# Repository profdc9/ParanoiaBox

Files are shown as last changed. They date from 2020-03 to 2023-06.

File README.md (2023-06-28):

# ParanoiaBox
The ParanoiaBox by Daniel L. Marks

The ParanoiaBox is a standalone open hardware/software encryption device based on the STM32F103CBT6 processor.  On this device, messages may be composed, encrypted, decrypted, and viewed.  The device is an experiment in encryption minimalism, presenting a minimal attack surface by using a small microcontroller rather than a full personal computer with a complex operating system, while providing the functionality needed to transact encrypted messages between humans through insecure networks.  The device is connected to a NTSC television and a PS/2 keyboard for user input and control.  There are two micro SD card slots, one for ciphertext and the other for plaintext used to transact files.  There is a hardware random number generator based on avalanche noise generated in two transistors.  A picture of the complete PCB of the device can be seen below:

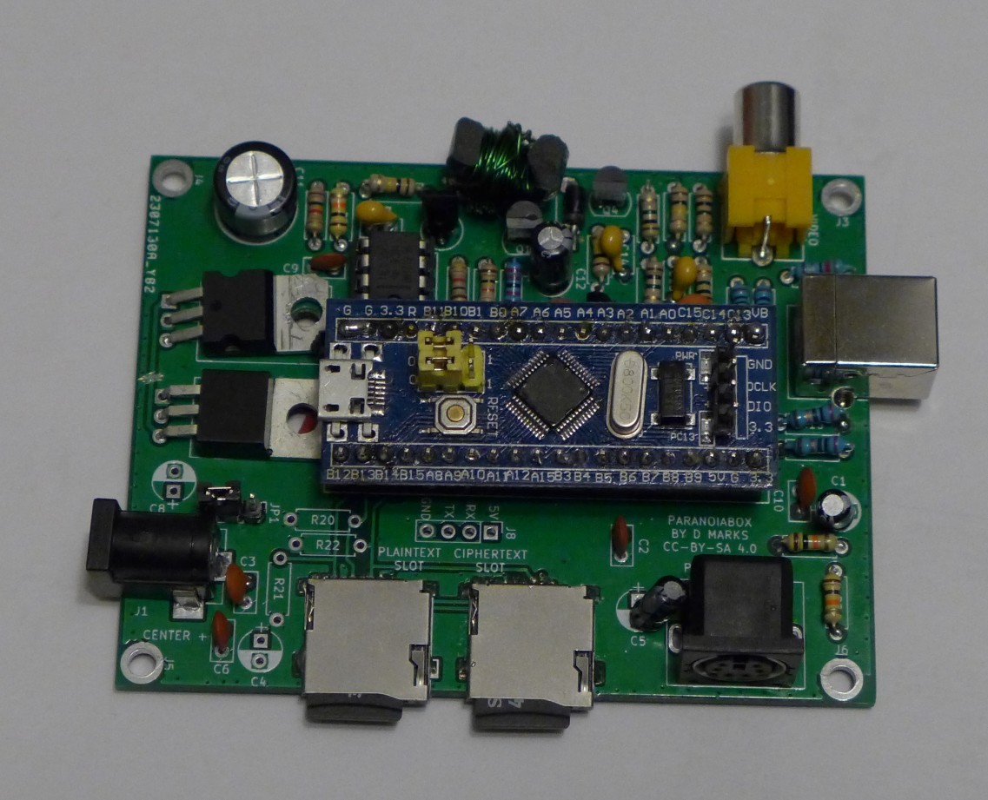
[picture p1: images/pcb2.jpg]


At the top of the board is a RCA composite video connector.  At the right is a USB B connector that can be used to program the microcontroller.  At the lower right is a female PS/2 keyboard connector.  At the bottom are two SD card slots.  Finally, at the left is a barrel jack for 7 to 12 volt DC input power.  Except for the micro SD card slots, the PCB is all through assembly so it can be assembled more easily using simple tools.

The hardware is licensed under the Creative Commons CC-BY-SA 4.0 license.  The software written by D. L. Marks is licensed under the zlib license.  All other libraries are licensed under the licenses as described in the corresponding source files.  This hardware and software is provided under these licenses to be used at your own risk.  

THE HARDWARE AND SOFTWARE IS PROVIDED "AS IS", WITHOUT WARRANTY OF ANY KIND, EXPRESS OR IMPLIED, INCLUDING BUT NOT LIMITED TO THE WARRANTIES OF MERCHANTABILITY, FITNESS FOR A PARTICULAR PURPOSE AND NONINFRINGEMENT. IN NO EVENT SHALL THE AUTHORS OR COPYRIGHT HOLDERS BE LIABLE FOR ANY CLAIM, DAMAGES OR OTHER LIABILITY, WHETHER IN AN ACTION OF CONTRACT, TORT OR OTHERWISE, ARISING FROM, OUT OF OR IN CONNECTION WITH THE HARDWARE AND SOFTWARE OR THE USE OR OTHER DEALINGS IN THE HARDWARE AND SOFTWARE.

The project uses Advanced Encryption Standard AES256-GCM Galois Counter Mode as an authenticated symmetric encryption.  The keys are derived from shared secrets based on then Elliptic Curve Diffie-Hellmann (ECDH) 25519.  The keys are encrypted using a passphrase and AES256-GCM and stored in the flash memory of the microcontroller.  The encrypted data and public key certificates are base64 encoded so that they can be transmitted through e-mail as text files.  The library used is the Arduino Cryptography Library by Rhys Weatherley:

https://rweather.github.io/arduinolibs/crypto.html

The project uses the stm32duino libraries located here:

https://github.com/rogerclarkmelbourne/Arduino_STM32

All other Arduino libraries are provided in the libraries directory in this project, including those that provide the FAT fs, NTSC video output, PS/2 keyboard input, and cryptography.  To enter a message into the microcontroller, there is a full-screen text editor:

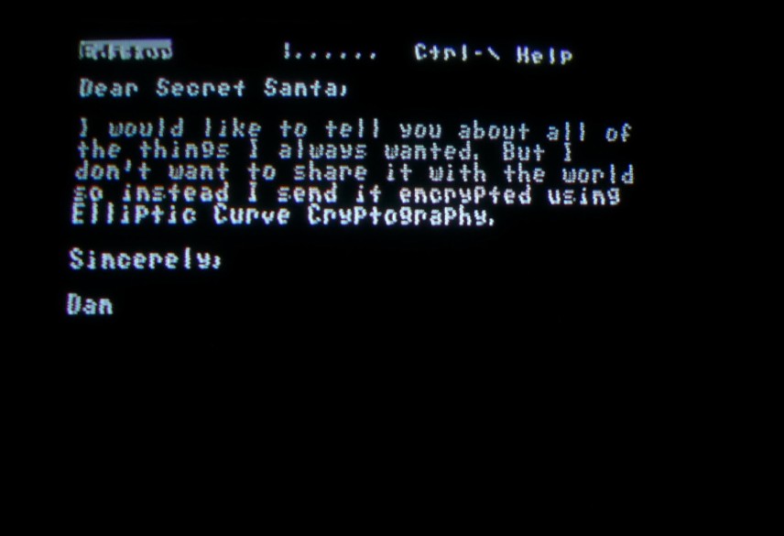
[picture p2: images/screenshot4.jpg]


There is a the built-in full-screen editor used to compose short messages.  Files may be selected from the SD cards for editing, encryption, or decryption:

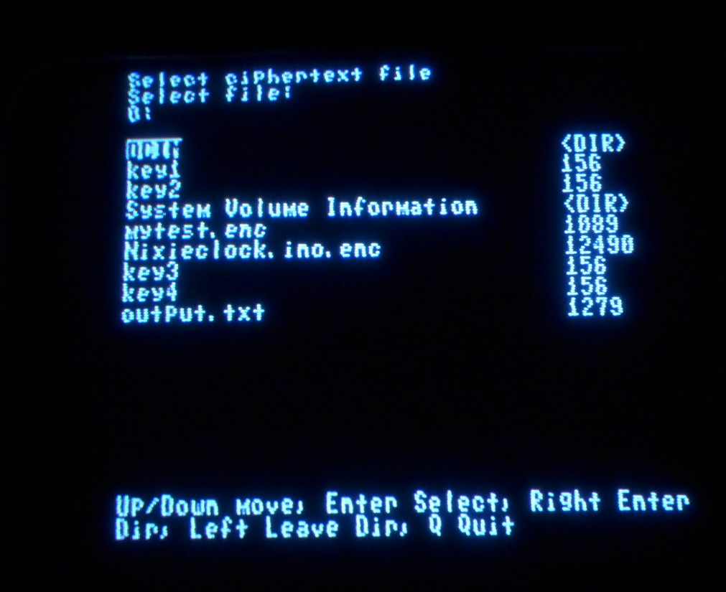
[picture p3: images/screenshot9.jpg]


This is the key manager screen from which the AES 256 symmetric, ECDH25519 private or public keys are selected:

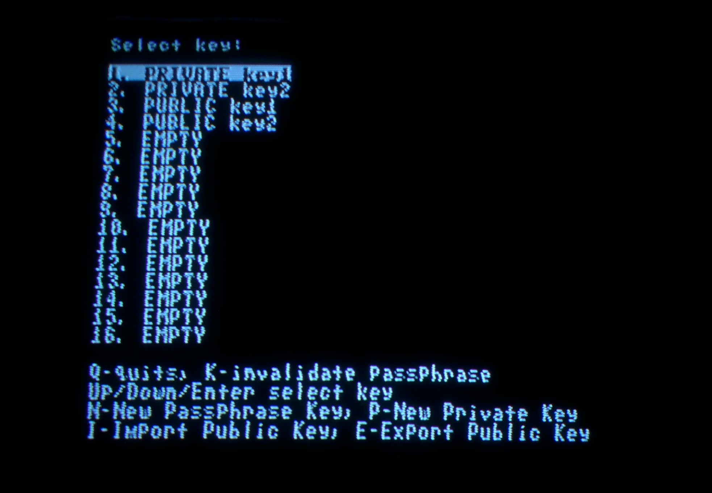
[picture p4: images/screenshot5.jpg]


To encrypt/decrypt using AES, a AES key is selected.  To encrypt/decrypt using ECDH25519, a private and public key pair are selected.   Then one selects a file to encrypt or decrypt.  Separate SD cards must be used for encryption and decryption to ensure that both are not available together to be compared.  One can export a public key certificate from a private key.  After selection, the main screen shows the selected keys:

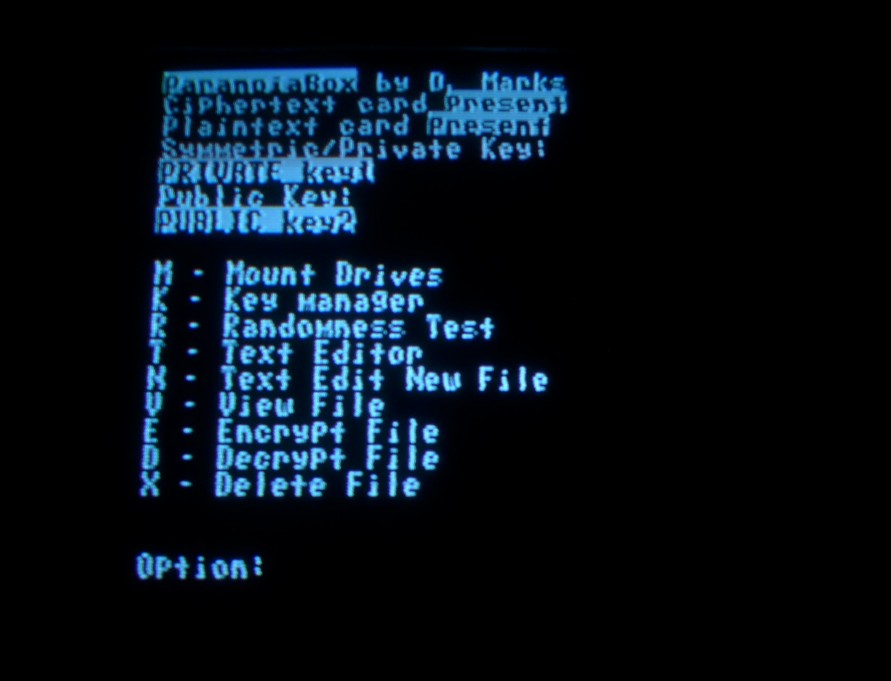
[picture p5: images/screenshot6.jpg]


The message is then encrypted by selecting the file from the card in the plaintext slot using the (E)ncrypt option.  Then the encrypted file is placed on the card in the ciphertext slot.  You can view this file which is text encoded to be easily transmitted over email:

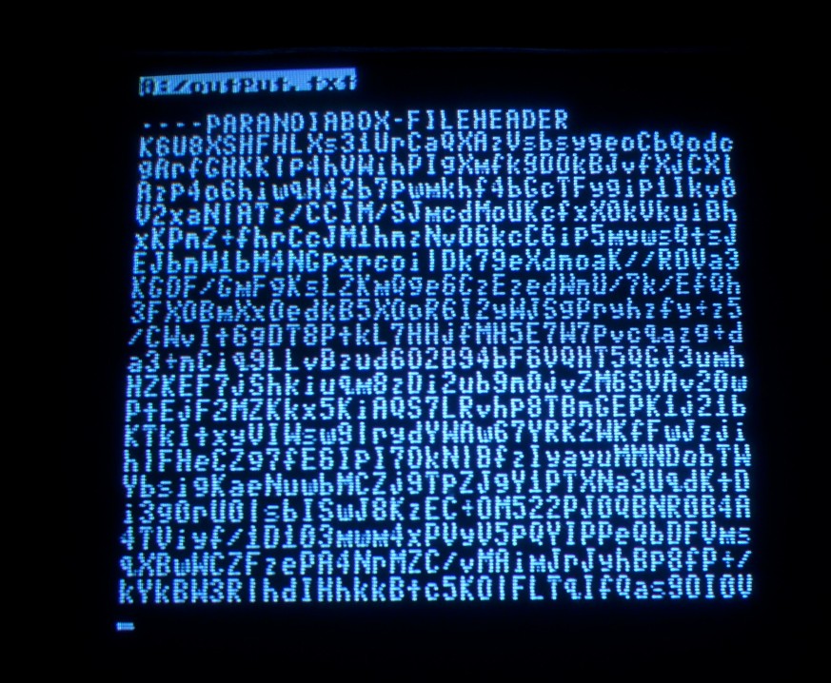
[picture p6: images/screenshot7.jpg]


Once it has been received, it can be decrypted and viewed, and it looks like the original:

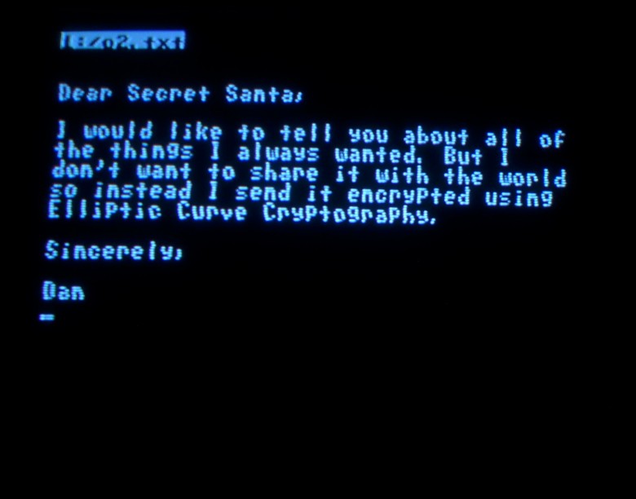
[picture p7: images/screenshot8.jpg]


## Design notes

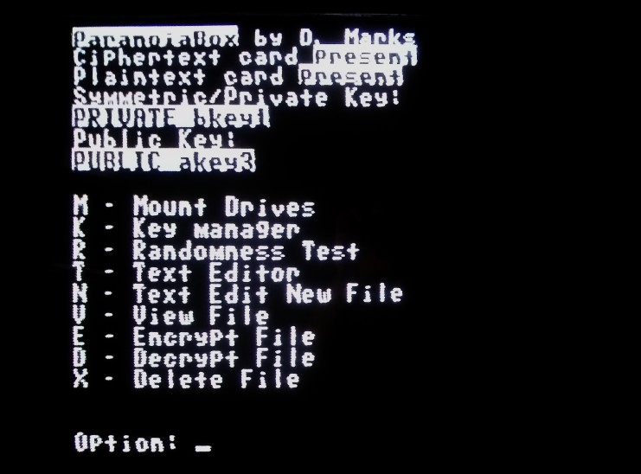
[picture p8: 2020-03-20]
images/screenshot1.jpg

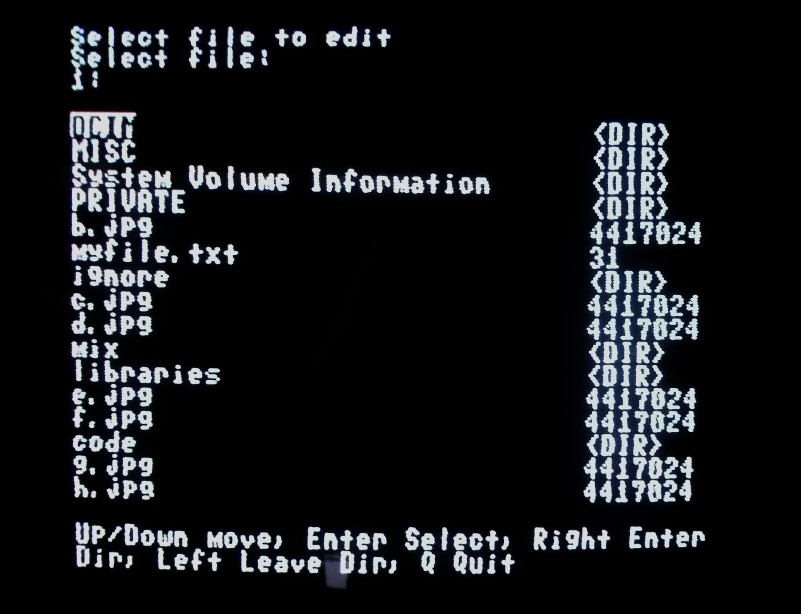
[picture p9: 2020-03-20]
images/screenshot2.jpg

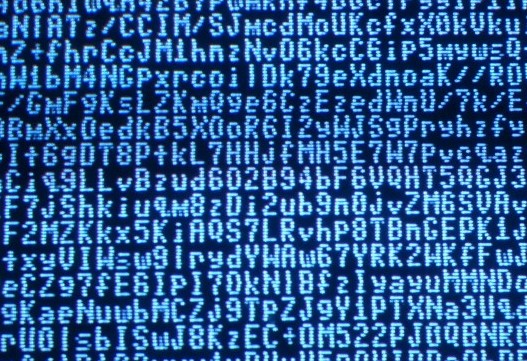
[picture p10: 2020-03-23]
images/background.jpg

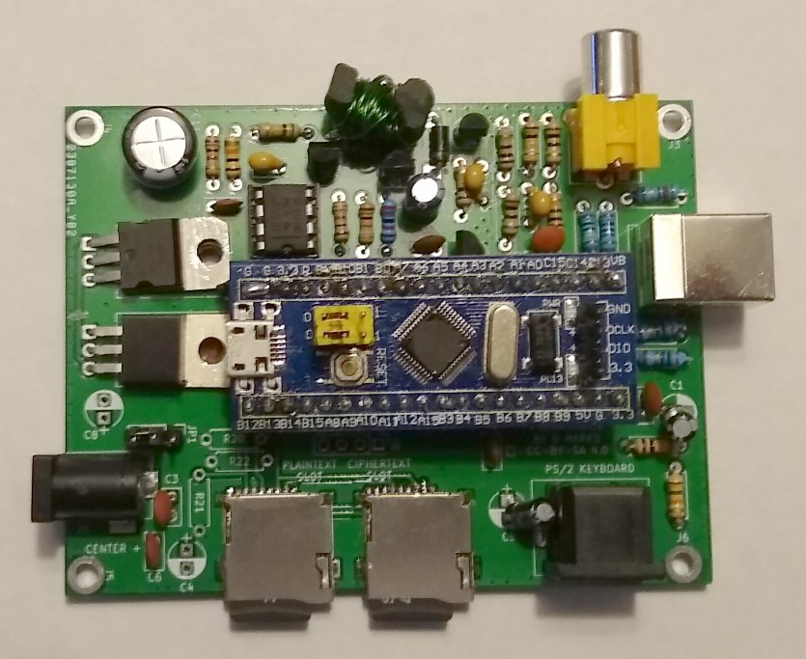
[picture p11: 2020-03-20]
images/pcb.jpg

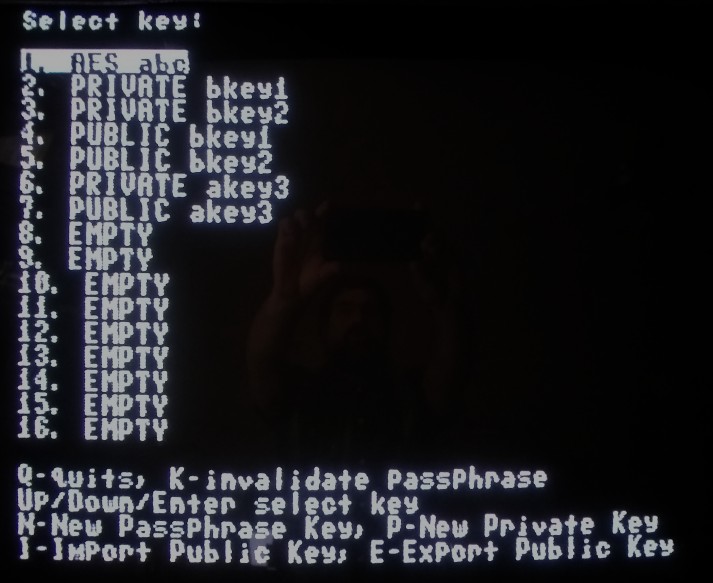
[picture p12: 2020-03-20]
images/screenshot3.jpg

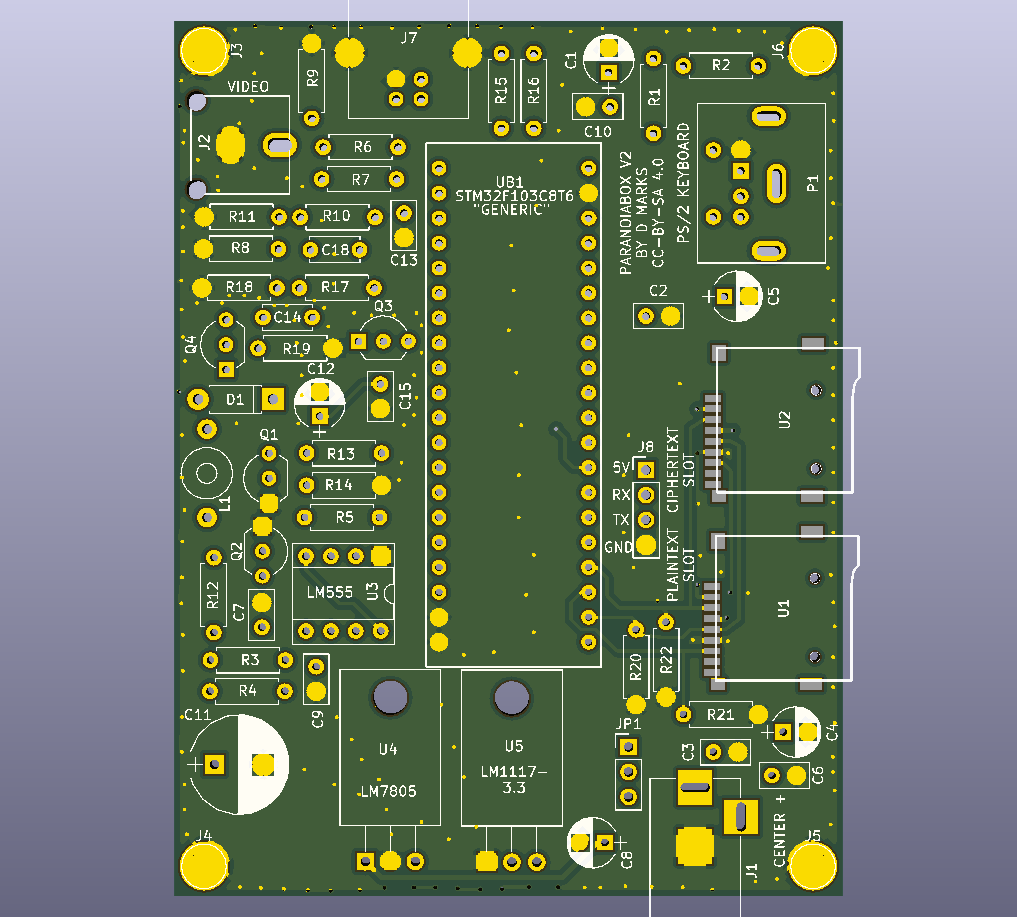
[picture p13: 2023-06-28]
board/ParanoiaBox-image.png

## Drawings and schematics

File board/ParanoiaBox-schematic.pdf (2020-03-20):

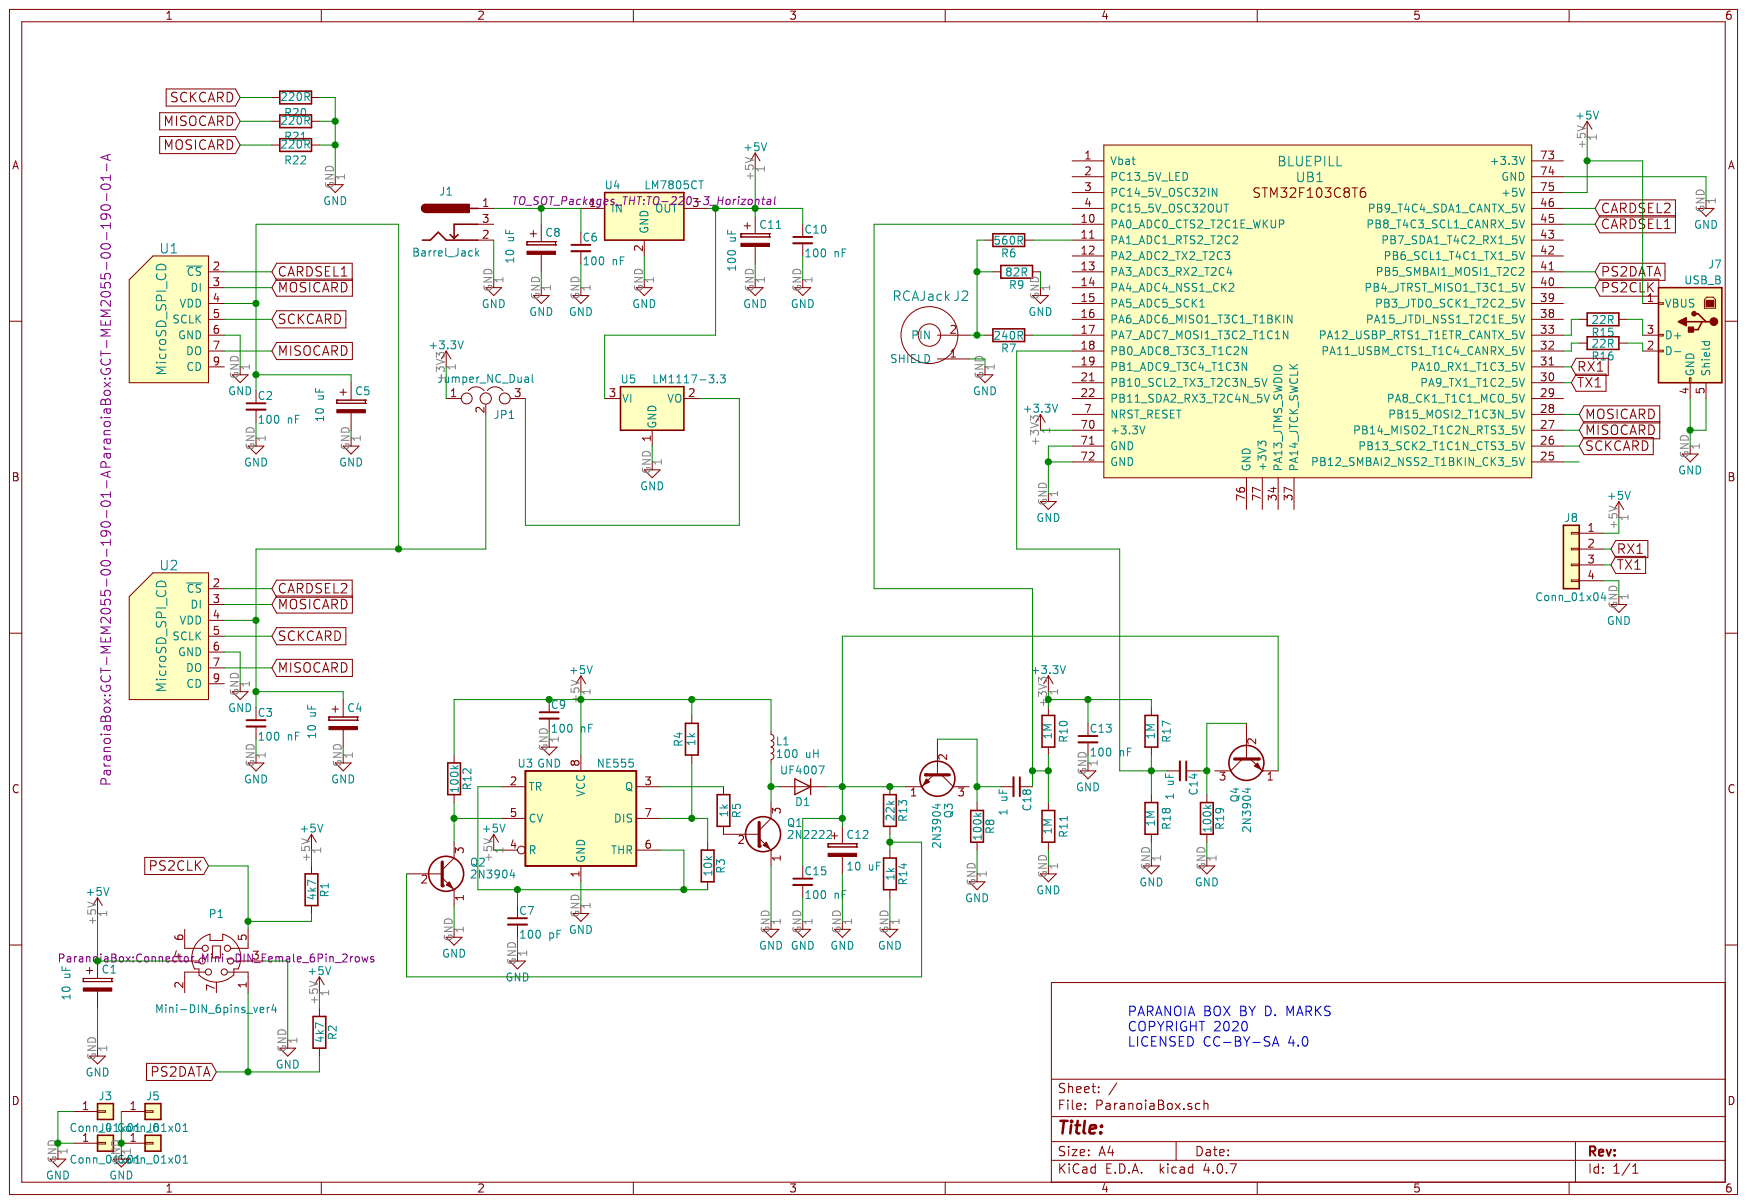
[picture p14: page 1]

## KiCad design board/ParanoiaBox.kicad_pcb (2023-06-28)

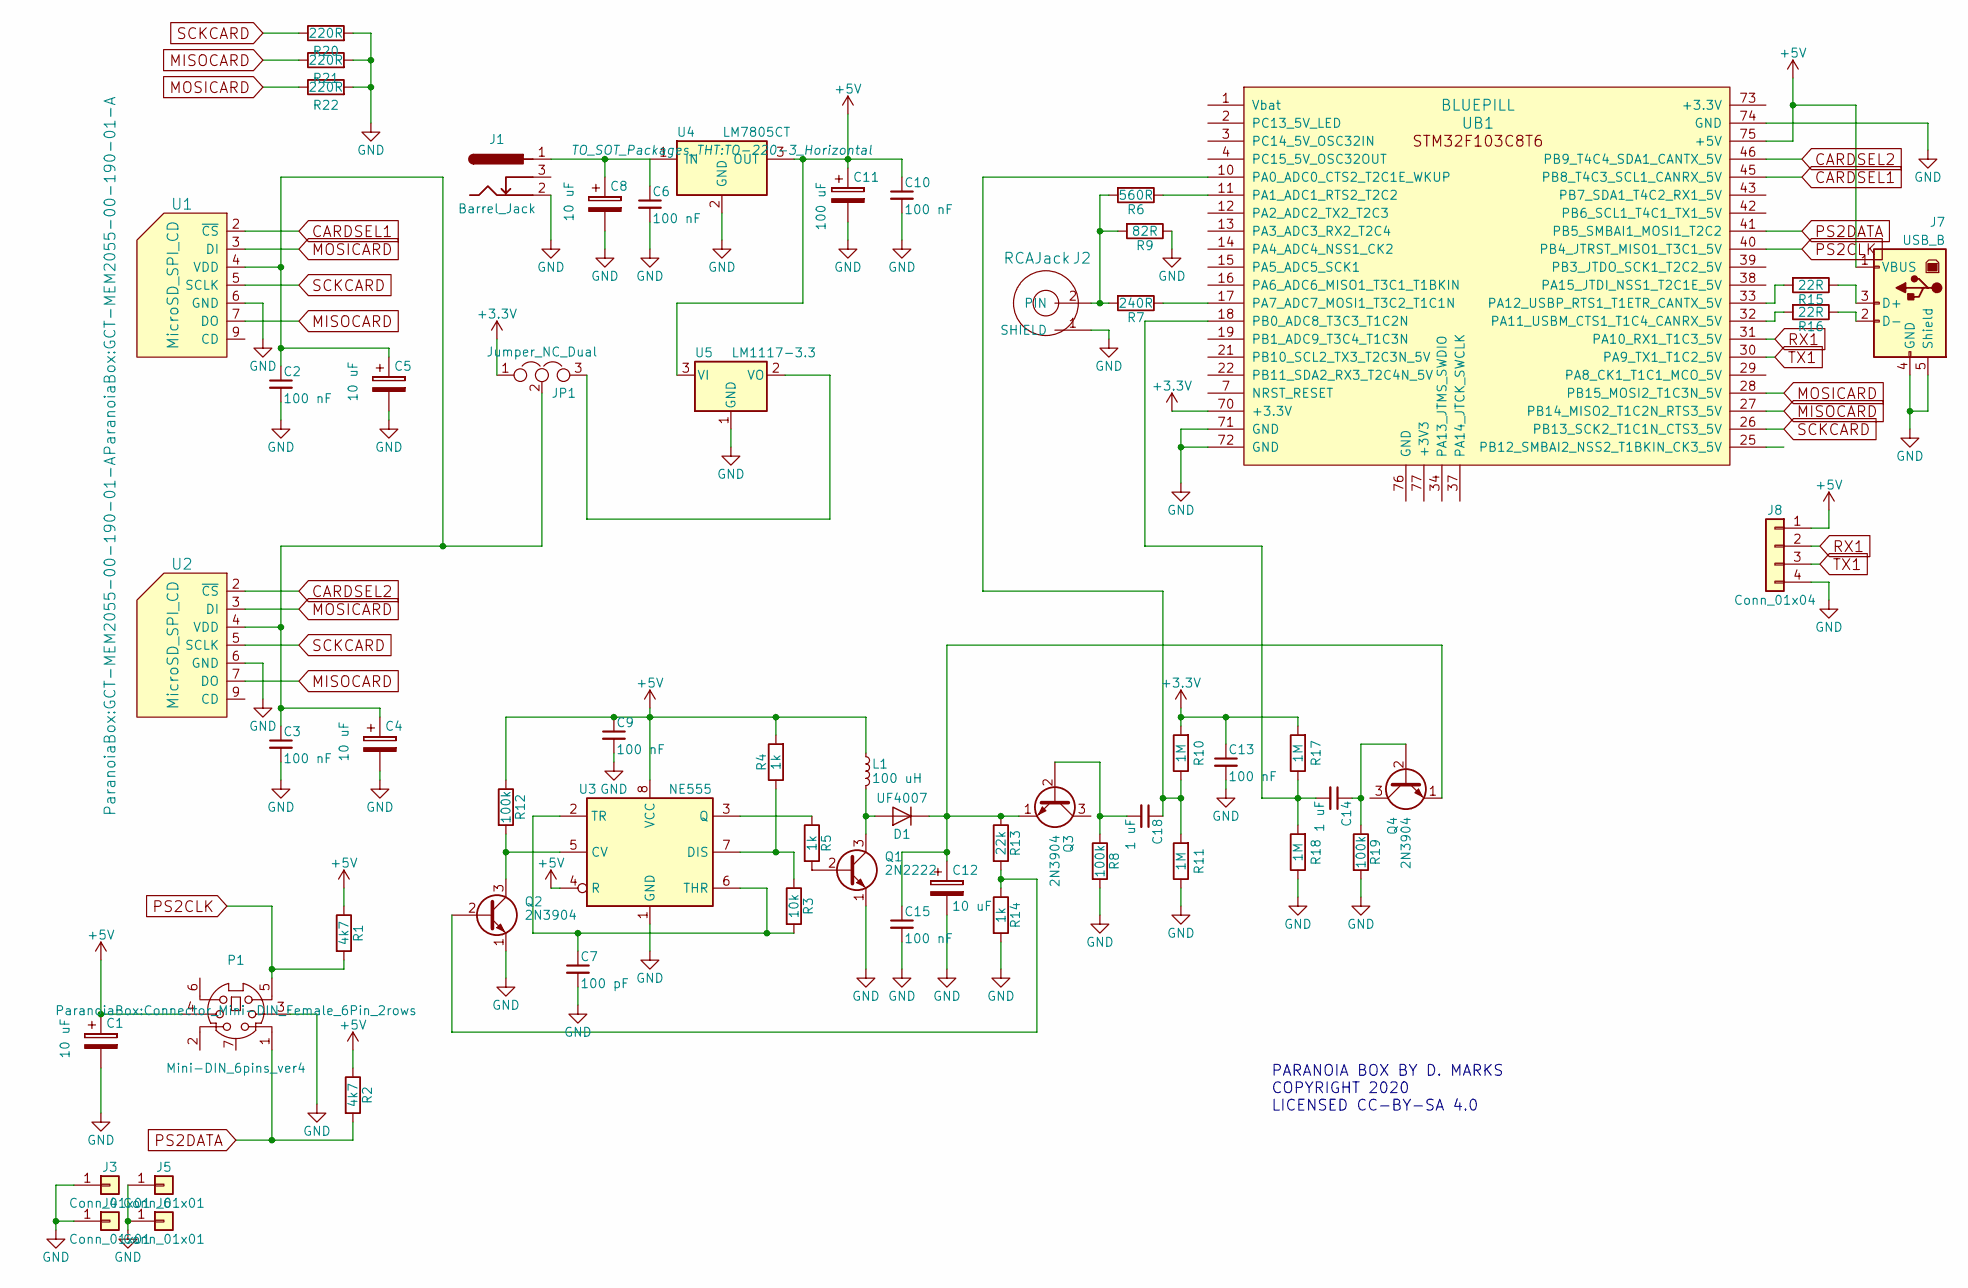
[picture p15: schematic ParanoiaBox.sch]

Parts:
C1, C4, C5, C8, C12: 10 uF; CP_Radial_D5.0mm_P2.50mm
C2, C3, C6, C9, C10, C13, C15: 100 nF; C_Disc_D5.0mm_W2.5mm_P2.50mm
C7: 100 pF; C_Disc_D5.0mm_W2.5mm_P2.50mm
C11: 100 uF; CP_Radial_D10.0mm_P5.00mm
C14, C18: 1 uF; C_Disc_D5.0mm_W2.5mm_P5.00mm
D1: UF4007; D_DO-41_SOD81_P7.62mm_Horizontal
J1: Barrel_Jack; BARREL_JACK
J2: RCAJack; RCAConnectorCommon
J3, J4, J5, J6: Conn_01x01; 1pin
J7: USB_B
J8: Conn_01x04; Pin_Header_Straight_1x04_Pitch2.54mm
JP1: Jumper_NC_Dual; Pin_Header_Straight_1x03_Pitch2.54mm
L1: 100 uH; L_Toroid_Horizontal_D5.1mm_P9.00mm_Diameter6-5mm_Amidon-T20
P1: Mini-DIN_6pins_ver4; Connector_Mini-DIN_Female_6Pin_2rows
Q1: 2N2222; TO-92_Inline_Wide
Q2, Q3, Q4: 2N3904; TO-92_Inline_Wide
R1, R2: 4k7; R_Axial_DIN0207_L6.3mm_D2.5mm_P7.62mm_Horizontal
R3: 10k; R_Axial_DIN0207_L6.3mm_D2.5mm_P7.62mm_Horizontal
R4, R5, R14: 1k; R_Axial_DIN0207_L6.3mm_D2.5mm_P7.62mm_Horizontal
R6: 560R; R_Axial_DIN0207_L6.3mm_D2.5mm_P7.62mm_Horizontal
R7: 240R; R_Axial_DIN0207_L6.3mm_D2.5mm_P7.62mm_Horizontal
R8, R12, R19: 100k; R_Axial_DIN0207_L6.3mm_D2.5mm_P7.62mm_Horizontal
R9: 82R; R_Axial_DIN0207_L6.3mm_D2.5mm_P7.62mm_Horizontal
R10, R11, R17, R18: 1M; R_Axial_DIN0207_L6.3mm_D2.5mm_P7.62mm_Horizontal
R13: 22k; R_Axial_DIN0207_L6.3mm_D2.5mm_P7.62mm_Horizontal
R15, R16: 22R; R_Axial_DIN0207_L6.3mm_D2.5mm_P7.62mm_Horizontal
R20, R21, R22: 220R; R_Axial_DIN0207_L6.3mm_D2.5mm_P7.62mm_Horizontal
U1, U2: MicroSD_SPI_CD; GCT-MEM2055-00-190-01-A
U3: NE555; DIP-8_W7.62mm_Socket
U4: LM7805CT; TO-220-3_Horizontal
U5: LM1117-3.3; TO-220-3_Horizontal
UB1: BLUEPILL

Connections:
+3V3: C13.1, JP1.1, R10.2, R17.2, UB1.70 (+3.3V)
+5V: C1.1, C9.1, C10.1, C11.1, J7.1 (VBUS), J8.1, L1.1, P1.4, R1.1, R2.1, R4.2, R12.1, U3.4 (R), U3.8 (VCC), U4.3 (OUT), U5.3 (VI), UB1.75 (+5V)
CARDSEL1: U1.2 (~CS), UB1.45 (PB8_T4C3_SCL1_CANRX_5V)
CARDSEL2: U2.2 (~CS), UB1.46 (PB9_T4C4_SDA1_CANTX_5V)
GND: C1.2, C2.2, C3.2, C4.2, C5.2, C6.2, C7.2, C8.2, C9.2, C10.2, C11.2, C12.2, C13.2, C15.2, J1.2, J2.1 (SHIELD), J3.1, J4.1, J5.1, J6.1, J7.4 (GND), J7.5 (Shield), J8.4, P1.3, Q1.1 (E), Q2.1 (E), R8.2, R9.1, R11.1, R14.2, R18.1, R19.2, R20.2, R21.2, R22.2, U1.6 (GND), U2.6 (GND), U3.1 (GND), U4.2 (GND), U5.1 (GND), UB1.71 (GND), UB1.72 (GND), UB1.74 (GND)
MISOCARD: R21.1, U1.7 (DO), U2.7 (DO), UB1.27 (PB14_MISO2_T1C2N_RTS3_5V)
MOSICARD: R22.1, U1.3 (DI), U2.3 (DI), UB1.28 (PB15_MOSI2_T1C3N_5V)
unnamed: C2.1, C3.1, C4.1, C5.1, JP1.2, U1.4 (VDD), U2.4 (VDD)
unnamed: C6.1, C8.1, J1.1, U4.1 (IN)
unnamed: C7.1, R3.2, U3.2 (TR), U3.6 (THR)
unnamed: C12.1, C15.1, D1.1 (K), Q3.1 (E), Q4.1 (E), R13.1
unnamed: C14.1, Q4.2 (B), R19.1
unnamed: C14.2, R17.1, R18.2, UB1.18 (PB0_ADC8_T3C3_T1C2N)
unnamed: C18.1, R10.1, R11.2, UB1.10 (PA0_ADC0_CTS2_T2C1E_WKUP)
unnamed: C18.2, Q3.2 (B), R8.1
unnamed: D1.2 (A), L1.2, Q1.3 (C)
unnamed: J2.2 (PIN), R6.2, R7.2, R9.2
unnamed: J7.2 (D-), R16.1
unnamed: J7.3 (D+), R15.1
unnamed: JP1.3, U5.2 (VO)
unnamed: Q1.2 (B), R5.2
unnamed: Q2.2 (B), R13.2, R14.1
unnamed: Q2.3 (C), R12.2, U3.5 (CV)
unnamed: R3.1, R4.1, U3.7 (DIS)
unnamed: R5.1, U3.3 (Q)
unnamed: R6.1, UB1.11 (PA1_ADC1_RTS2_T2C2)
unnamed: R7.1, UB1.17 (PA7_ADC7_MOSI1_T3C2_T1C1N)
unnamed: R15.2, UB1.33 (PA12_USBP_RTS1_T1ETR_CANTX_5V)
unnamed: R16.2, UB1.32 (PA11_USBM_CTS1_T1C4_CANRX_5V)
PS2CLK: P1.5, R1.2, UB1.40 (PB4_JTRST_MISO1_T3C1_5V)
PS2DATA: P1.1, R2.2, UB1.41 (PB5_SMBAI1_MOSI1_T2C2)
RX1: J8.2, UB1.31 (PA10_RX1_T1C3_5V)
SCKCARD: R20.1, U1.5 (SCLK), U2.5 (SCLK), UB1.26 (PB13_SCK2_T1C1N_CTS3_5V)
TX1: J8.3, UB1.30 (PA9_TX1_T1C2_5V)

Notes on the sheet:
PARANOIA BOX BY D. MARKS COPYRIGHT 2020 LICENSED CC-BY-SA 4.0

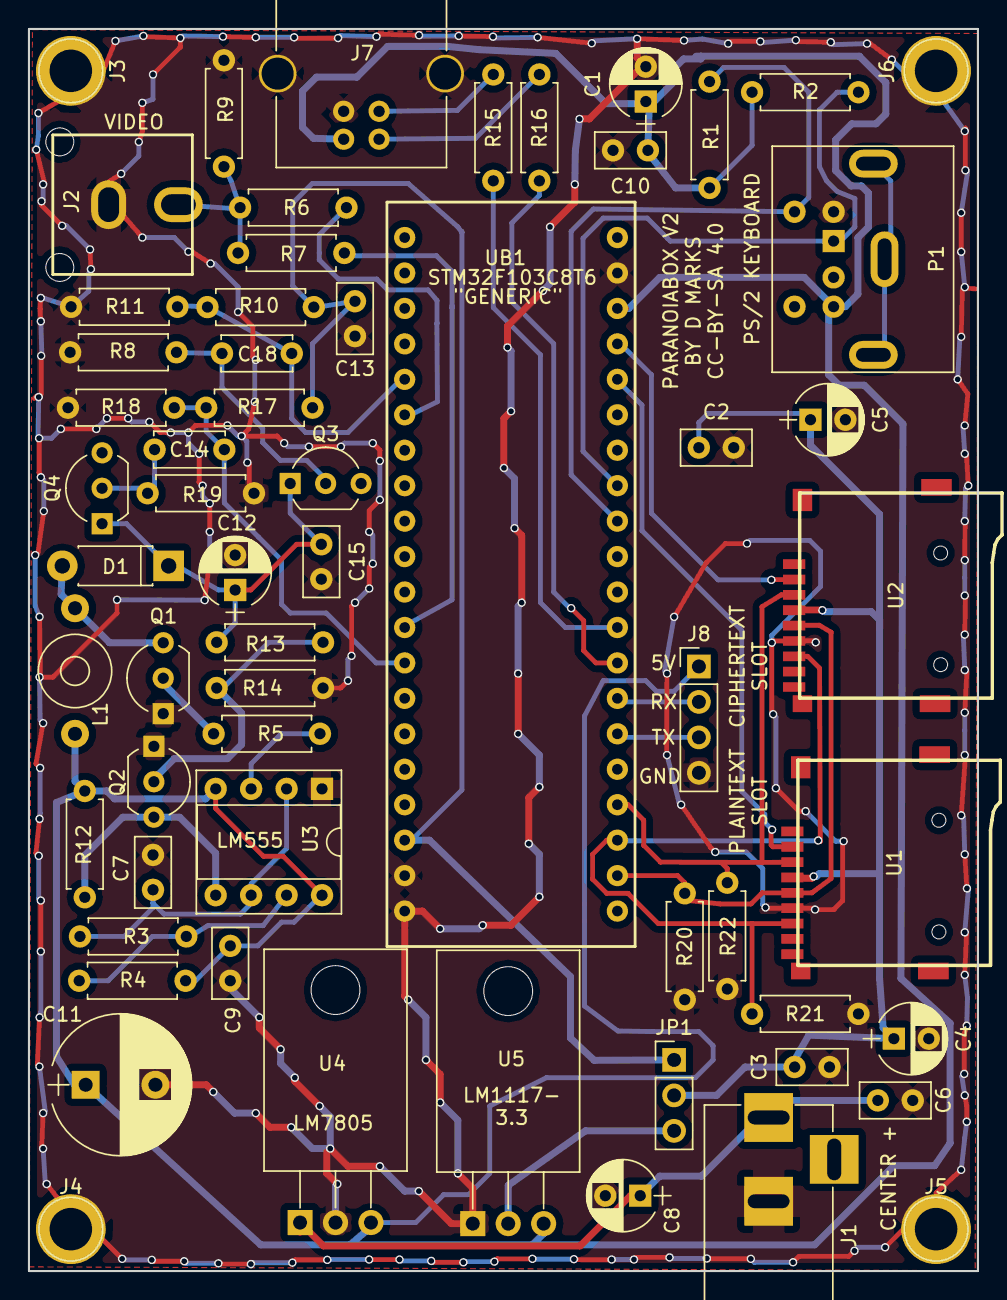
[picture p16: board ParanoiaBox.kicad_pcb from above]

Board: 2 copper layers, 68.0 x 89.0 mm, 60 parts (0 on the bottom side), 34 nets.

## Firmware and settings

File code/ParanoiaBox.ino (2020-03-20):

#include <Arduino.h>
#include <malloc.h>
#include <SPI.h>
#include <ff.h>

#include "consoleio.h"
#include "debugmsg.h"
#include "mini-printf.h"
#include "editor.h"
#include "random.h"
#include "fileop.h"
#include "keymanager.h"
#include "fileenc.h"

void setup() {
  digitalWrite(PB8, HIGH); // Put CS lines for card HIGH right away to avoid confusion
  digitalWrite(PB9, HIGH);
  pinMode(PB8, OUTPUT);
  pinMode(PB9, OUTPUT);
  Serial.begin(115200);
  random_initialize();
  console_init();
  keymanager_initialize();
}

const char mainmenu[] =
  "\r\n\r\nM - Mount Drives\r\n\
K - Key manager\r\n\
R - Randomness Test\r\n\
T - Text Editor\r\n\
N - Text Edit New File\r\n\
V - View File\r\n\
E - Encrypt File\r\n\
D - Decrypt File\r\n\
X - Delete File\r\n\
\r\n\r\nOption: ";

const char mainmenuoptions[] = "MKRTNVEDZX";

void loop()
{
  console_clrscr();
  console_highvideo();
  console_puts("ParanoiaBox");
  console_lowvideo();
  console_puts(" by D. Marks\r\n");
  console_puts("Ciphertext card ");
  console_highvideo();
  console_puts(fs0_mounted ? "present" : "absent");
  console_lowvideo();
  console_puts("\r\nPlaintext card ");
  console_highvideo();
  console_puts(fs1_mounted ? "present" : "absent");
  console_lowvideo();
  console_puts("\r\nSymmetric/Private Key:\r\n");
  console_highvideo();
  keymanager_display_key(-1, &current_key_private);
  console_lowvideo();
  console_puts("\r\nPublic Key:\r\n");
  console_highvideo();
  keymanager_display_key(-1, &current_key_public);
  console_lowvideo();
/*  console_puts(" heapstack: ");
  console_printint(heap_stack_distance());
  console_printcrlf(); */
  int option = console_selectmenu(mainmenu, mainmenuoptions);
  delay(500);
  switch (option)
  {
    case 'R': randomness_test();
      break;
    case 'K': keymanager();
      break;
    case 'X': file_delete();
      break;
    case 'N': file_new();
      break;
    case 'T': file_edit();
      break;
    case 'M': file_mount_volume(0);
      break;
    case 'V': file_view();
      break;
    case 'E': fileenc_encrypt();
      break;
    case 'D': fileenc_decrypt();
      break;
    case 'Z': randomness_show();
      break;

  }
}

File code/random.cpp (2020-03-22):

/*
 * Copyright (c) 2020 Daniel Marks

This software is provided 'as-is', without any express or implied
warranty. In no event will the authors be held liable for any damages
arising from the use of this software.

Permission is granted to anyone to use this software for any purpose,
including commercial applications, and to alter it and redistribute it
freely, subject to the following restrictions:

1. The origin of this software must not be misrepresented; you must not
   claim that you wrote the original software. If you use this software
   in a product, an acknowledgment in the product documentation would be
   appreciated but is not required.
2. Altered source versions must be plainly marked as such, and must not be
   misrepresented as being the original software.
3. This notice may not be removed or altered from any source distribution.
 */

#include <stdarg.h>
#include <Arduino.h>
#include <RNG.h>
#include "SimpleTransistorNoiseSource.h"
#include "debugmsg.h"
#include "consoleio.h"
#include "random.h"
#include "cryptotool.h"

#define AD_RAND_PIN1 0   /* PA0 */
#define AD_RAND_PIN2 8   /* PB0 */

#define USE_MINIPRINTF

#ifdef USE_MINIPRINTF
#include "mini-printf.h"
#endif

SimpleTransistorNoiseSource noise;

#ifdef __cplusplus
extern "C" {
#endif

#define ROTATE8BITSLEFT(x) (((uint8_t)(x) << 1) | ((uint8_t)(x) >> 7))

void randomness_get_raw_random_bits(uint8_t randomdata[], int bytes)
{
  while (bytes>0)
  {
    ADC1->regs->SQR3 = AD_RAND_PIN1;
  	ADC1->regs->CR2 |= ADC_CR2_SWSTART;
    ADC2->regs->SQR3 = AD_RAND_PIN2;
  	ADC2->regs->CR2 |= ADC_CR2_SWSTART;
  	while (!(ADC1->regs->SR & ADC_SR_EOC));
  	randomdata[--bytes] = ((unsigned char)(ADC1->regs->DR & ADC_DR_DATA));
  	while (!(ADC2->regs->SR & ADC_SR_EOC));
    if (bytes>0) randomdata[--bytes] = ((unsigned char)(ADC2->regs->DR & ADC_DR_DATA));
  }
}

void random_initialize(void)
{
	pinMode(PA0,INPUT_ANALOG);
	pinMode(PB0,INPUT_ANALOG);
	adc_set_sample_rate(ADC1, ADC_SMPR_1_5);
	adc_set_reg_seqlen(ADC1, 1);
	adc_set_sample_rate(ADC2, ADC_SMPR_1_5);
	adc_set_reg_seqlen(ADC2, 1);

  RNG.begin(RNG_APP_TAG);
  RNG.addNoiseSource(noise);
}

void random_stir_in_entropy(void)
{
  while (!RNG.available(32))
    RNG.loop();
}

int random_circuit_check(void)
{
}

/*
void randomness_get_whitened_bits(uint8_t whitenedbytes[], size_t bytes)
{
	for (int b=0;b<bytes;b+=32)
	{
    uint8_t predigest[KEYMANAGER_HASHLEN*8];   
		randomness_get_raw_random_bits(predigest, sizeof(predigest));
    int digest_bytes = bytes - b;
    ctblake2s(&whitenedbytes[b],
       digest_bytes > KEYMANAGER_HASHLEN ? KEYMANAGER_HASHLEN : digest_bytes,
       (void *)predigest, sizeof(predigest), NULL,0);
	}
}
*/

void randomness_get_whitened_bits(uint8_t whitenedbytes[], size_t bytes)
{
  for (int b=0;b<bytes;b+=32)
  {
    int get_bytes = bytes - b;
    get_bytes =  get_bytes > 32 ? 32 : get_bytes;
    while (!RNG.available(32))
      RNG.loop();
    RNG.rand(&whitenedbytes[b], get_bytes);
  }
}


#define NUMBER_BLOCK 400

void randomness_test(void)
{
  unsigned int histogram[32];
  for (int n=0;n<(sizeof(histogram)/sizeof(int));n++) histogram[n] = 0;
  unsigned long startime = millis();

  unsigned int bits=0;
  for (;;)
  {
	int ch = console_inchar();
	if (ch == ' ') break;
	for (int n=0;n<NUMBER_BLOCK;n++)
	{
		uint8_t randbits[32];
//		randomness_get_raw_random_bits(randbits, sizeof(randbits));
	    randomness_get_whitened_bits(randbits, sizeof(randbits));
	    for (int j=0;j<sizeof(randbits);j++)
			histogram[randbits[j] & 0x1F]++;
	}
  bits += (NUMBER_BLOCK*32*8);
	console_clrscr();
	console_puts("Histogram:\r\n\n");
	for (int n=0;n<16;n++)
	{
    console_gotoxy(1,n+3);
		console_printint(n);
		console_puts(": ");
		console_printuint(histogram[n]);
    console_gotoxy(20,n+3);
    console_printint(n+16);
    console_puts(": ");
    console_printuint(histogram[n+16]);
	} 
  unsigned long elapsed = ((unsigned long)(millis()-startime))/1000;
  console_gotoxy(1,20);
  console_puts("Total bits: ");
  console_printuint(bits);
  console_puts(" bit/s ");
  console_printuint(bits/elapsed);
	console_puts("\r\nPress SPACE to end");
  }	  
}

void randomness_show(void)
{
	for (;;)
	{
	  uint8_t samp[32];
    //  randomness_get_whitened_bits(samp, sizeof(samp));
    randomness_get_raw_random_bits(samp, sizeof(samp));
	  console_clrscr();
	  for (int i=0;i<(sizeof(samp)/sizeof(samp[0]));i+=2)
	  {
		  console_printuint(samp[i]);
		  console_puts(" ");
		  console_printuint(samp[i+1]);
		  console_printcrlf();		  
	  }
	  delay(1000);
	  int ch = console_inchar();
	  if (ch == ' ') break;
	}
}

#ifdef __cplusplus
}
#endif
